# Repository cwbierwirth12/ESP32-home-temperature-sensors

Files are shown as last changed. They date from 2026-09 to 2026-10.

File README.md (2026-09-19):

# ESP32-Home-Temperature-Sensors

The purpose of this project is to deploy small ESP32 temperature and humidity sensors throughout your home and monitor them over your local network. This project uses ESPHome firmware, a Mosquitto MQTT broker, and a Node-RED diagnostic dashboard. ESPTH is the collection-only device utilizing an ESP32-C6 board; ESPTHSC adds a desktop display and online weather on an ESP32-S3 board. Home Assistant is an optional adaptation to be able to see your sensors, with no setup instructions included here.

This project is not turn-key. Users will need to configure the sensors for their home networks and make any adjustments necessary. Additionally the chips, boards, sensors all come bare bones and need to be assembled. 3D STL files are available for download to 3D print enclosures. At this time I do not know of any commercially available enclosures.

## Quickstart

1. Build the physical sensor (screen or no screen)
2. Copy `firmware/secrets.example.yaml` to private `firmware/secrets.yaml` and configure your network and location.
3. Compile the matching YAML with ESPHome and flash the resulting firmware over USB.
4. Choose a [Node-RED build](nodered/): a small one-sensor diagnostic flow or an always-on Raspberry Pi dashboard with SQLite history.
5. Connect sensors to power source
6. Connect to the Node-Red dashboard in your browser to monitor the temperatures. 

## Project Folders

  [firmware](firmware/) - ESPHome YAML templates, wiring pinouts, and USB/OTA installation instructions. ESPHome compiles the firmware; ESPHome Web flashes a compiled file. Private `secrets.yaml` and generated firmware are excluded by `.gitignore`.

  [Node-RED](nodered/) - Contains both a basic one-sensor diagnostic flow and a Raspberry Pi Zero 2W standalone build with multi-sensor SQLite history.

  [hardware](hardware/) - BOMs, Photos, and 3D STL files for the sensors

## Network and Ports

```text
Sensor
    |
    |
Home Network ------- Home Assistant (optional; instructions not included)
    |
    |
MQTT Broker
    |
    |
    |
Node-RED
```

| Service | Port | Used by |
| --- | --- | --- |
| MQTT broker | TCP `1883` | ESP32 devices and Node-RED connect to Mosquitto. |
| Node-RED editor and dashboard | TCP `1880` by default | Browser connects to the Node-RED computer; the port may differ if the user changed their Node-RED configuration. |
| ESPHome Device Builder | TCP `6052` by default | Browser connects to the firmware-building computer. |
| ESPHome OTA | TCP `3232` by default on ESP32 | ESPHome uploads firmware to a sensor with OTA enabled. |

For a standard local Node-RED installation, the editor is [localhost:1880](http://localhost:1880). The basic diagnostic flow uses `/dashboard/diagnostics`; the Raspberry Pi standalone build uses `/dashboard/temperature-history`. Use the port configured by your own installation if it differs. Use the server's LAN address from another device. No router port forwarding is required. Screen weather and time synchronization need internet access; local MQTT sensor collection does not.

## Tools and Software

- Firmware: ESPHome Device Builder; Docker is optional.
- DNode-Red Dashboard: a user-installed Node-RED instance plus the FlowFuse Dashboard add-on. Import the supplied diagnostic flow through the Node-RED editor.
- MQTT Broker: Mosquitto and its command-line clients.
- Enclosures: a 3D slicer of your choice.

Instructions for download and installation are found in each of the respective subfolders.

## Project Status and Disclosure

- I am not a programmer. Firmware, flow code, and documentation were developed with AI assistance. See [NOTICE.md](NOTICE.md) for attribution, third-party licenses, and testing limitations.

- This project is provided without warranty and is not intended for life-safety systems.

- This project is actively evolving. The screen enclosure is still in development, and the [firmware limitations](firmware/README.md#known-limitations) need review before calling the display firmware release-ready. Back up working configurations before upgrading.

- See the [publication review](AUDIT.md) for the checks performed, tested versions, and remaining hardware-validation work.

- Original project material is licensed under GNU GPL version 3 only (`GPL-3.0-only`). See [LICENSE](LICENSE) and [NOTICE.md](NOTICE.md). Third-party materials retain their own licenses.

# Project Thanks

- Huge thank you to my Sister for getting these components for me for Christmas 2025. Love you, sis.
- Thank you to my wife, for dealing with and embracing my nerdy endeavors.

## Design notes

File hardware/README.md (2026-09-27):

# Hardware and Enclosures

This folder documents the physical parts and 3D-printed enclosures for the two ESP32 Home Temperature Sensor variants:

- **ESPTH**: a compact, no-screen temperature and humidity sensor intended for data collection.
- **ESPTHSC**: a screen-equipped small temperature and humidity display intended for desktop use.

The firmware setup, pin wiring, and software configuration are documented in the [firmware README](../firmware/README.md).

## Contents

- [ESPTH bill of materials](#espth-bill-of-materials)
- [ESPTHSC bill of materials](#espthsc-bill-of-materials)
- [ESPTHSC display and controls](#espthsc-display-and-controls)
- [Enclosures and assembly](#enclosures-and-assembly)
- [3D-printing guidance](#3d-printing-guidance)
- [Troubleshooting](#troubleshooting)
- [Availability](#availability)

## ESPTH bill of materials

The no-screen ESPTH is the small, collection-only sensor.

| Part | Notes |
| --- | --- |
| [Waveshare ESP32-C6-Zero](https://www.waveshare.com/product/mcu-tools/development-boards/esp32-c6-zero.htm) | The ESP32 controller board used for this build. |
| [Waveshare DHT22 temperature and humidity sensor](https://www.waveshare.com/dht22-temperature-humidity-sensor.htm) | Measures local temperature and humidity. |
| USB-C data/power cable | Use a cable that supports data for the initial firmware flash. A charge-only cable will not work for flashing. |
| Regulated 5 V USB power source, 1 A or greater recommended | This is a practical adapter recommendation for the project, not a published Waveshare minimum current requirement. See the power notes below. |
| [ESPTH STL files](./3D%20Print/espth_files/STL/) | Base, lid, and two holding plates. [Editable STEP files](./3D%20Print/espth_files/STEP/) are also included. |
| Sensor wiring | Three conductors for power, ground, and data; choose connectors or soldered leads to fit the enclosure. |
| M2 x 4 mm and M2 x 6 mm screws | The enclosure is designed around these sizes. This [M2 screw kit](https://www.amazon.com/dp/B0D3X4LJD2) is the set used during development. |

## ESPTHSC bill of materials

The ESPTHSC is the screen-equipped version. It shows local and remote weather information and is intended to live on a desk, shelf, or other visible spot.

| Part | Notes |
| --- | --- |
| [Waveshare ESP32-S3-LCD-1.9](https://www.waveshare.com/esp32-s3-lcd-1.9.htm) | ESP32-S3 board with built-in 1.9-inch display. |
| [Waveshare DHT22 temperature and humidity sensor](https://www.waveshare.com/dht22-temperature-humidity-sensor.htm) | Measures local temperature and humidity. |
| USB-C data/power cable | Use a data-capable cable for the first firmware flash. |
| Regulated 5 V USB power source, 1 A or greater recommended | Practical adapter recommendation; actual current varies with display, Wi-Fi, peripherals, and battery charging. |
| Optional 3.7 V 450 mAh 502535 LiPo battery | The [example battery](https://www.amazon.com/dp/B0GDQMKQ36) is useful as short-term backup power while moving the display between rooms or disconnecting it from a computer. It is not intended to replace normal USB power. **Check the connector before ordering:** Waveshare documents an MX1.25 battery header on this board, while this example battery is listed with a JST-PH 2.0 connector. Use an appropriate adapter or a battery with the correct connector; never force a connector. |
| ESPTHSC enclosure files | Still in development; files will be added under [3D Print](./3D%20Print/) when ready. No screen STL or STEP files are currently included. |
| Sensor wiring | Three conductors for power, ground, and data. The supplied firmware uses `GPIO6` for the DHT22 data line. |
| M2 x 4 mm and M2 x 6 mm screws | This [M2 screw kit](https://www.amazon.com/dp/B0D3X4LJD2) is the set used during development. |

## ESPTHSC display and controls

The ESPTHSC firmware is configured for desktop use with the USB-C connector at the **9 o'clock / left-hand** side. It automatically advances every 20 seconds through this sequence:

1. Indoor temperature and humidity from the DHT22.
2. Indoor versus outside temperature comparison.
3. Current outdoor conditions, including wind speed and compass direction.
4. 12-hour outlook with two-hour samples for temperature, weather, precipitation, wind, and gust alerts.
5. Five-day forecast.
6. Moon phase.
7. Clock, network status, and battery estimate.

The physical **BOOT** button controls the display:

- **One short press:** wakes the display and advances to the next view. If clock-only mode is active, it exits that mode and returns to the indoor view.
- **Two short presses:** toggles clock-only mode. Enabling it opens the clock immediately; disabling it returns to the indoor view.
- **Press and hold for at least one second:** blanks the display. A later short press wakes it.

The short-press action waits 400 ms before it runs so the firmware can reliably distinguish a single press from a double press.

## Raspberry Pi Zero 2W Standalone  (OPTIONAL)

| Part | Notes |
| --- | --- |
| [Raspberry Pi Zero 2 W](https://www.waveshare.com/product/raspberry-pi/boards-kits/raspberry-pi-zero-2-w-cat/raspberry-pi-zero-2-w.htm) | |
| [32 GB SD Card](https://www.amazon.com/SanDisk-Ultra%C2%AE-microSDHC-120MB-Class/dp/B08L5HMJVW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)| |
| Micro-USB Cable |
| Regulated 5 V USB power source, 2.5 A or greater recommended | Practical adapter recommendation; actual current varies with display, Wi-Fi, peripherals, and battery charging. |

### Power and Battery Notes

Waveshare's [C6-Zero FAQ](https://docs.waveshare.com/ESP32-C6-Zero/FAQ) associates USB instability with supply voltage falling below 4.9 V. Its [board description](https://docs.waveshare.com/ESP32-C6-Zero) lists an 800 mA maximum output for the onboard 3.3 V regulator; that is not the board's measured current draw or a USB-adapter requirement. A regulated 5 V adapter rated for 1 A or more is the project's practical starting recommendation for either build. A higher current rating provides capacity; the board draws what it needs.

The [screen-board documentation](https://docs.waveshare.com/ESP32-S3-LCD-1.9) specifies a 3.7 V battery interface with an MX1.25 connector. The linked battery's JST-PH 2.0 plug is not a direct fit. Before use, verify the exact connector, positive/negative polarity, cell charging limits, and available case space. An adapter's physical fit alone does not establish electrical compatibility. Do not compress, puncture, or use a damaged or swollen LiPo cell.

The optional battery is intended to bridge short USB disconnections while moving the display. Continued power can preserve its in-memory state, but uninterrupted operation and runtime have not been verified for the linked pack. It does not preserve Wi-Fi connectivity between networks, guarantee MQTT delivery, or provide historical data storage.

## Enclosures and assembly

The current printable ESPTH files are in [3D Print/espth_files](./3D%20Print/espth_files/). Flash, configure, and test the boards before closing the enclosure. Disconnect USB and any battery before wiring or assembly. [Build photos](./Photos/espth/) show the no-screen enclosure.

- The STL filenames identify their purpose: base, lid, ESP32-C6 holding plate, and DHT22 holding plate.
- The thin holding plates secure the electronics inside the case.
- Use **M2 x 4 mm** screws for the internal holding plates.
- Use **M2 x 6 mm** screws to attach the lid to the base.
- The screw holes are countersunk for the heads in the recommended screw kit.
- Editable STEP versions are included for anyone who wants to adapt the design for different hardware, mounting locations, or preferences.

The ESPTHSC enclosure is currently in development and will be released here once it is ready.

## 3D-printing guidance

These enclosures are not highly structural parts, so use the material and printer settings that work best for you.

- PLA or PETG can be used; PETG is the maintainer's preference. Choose settings appropriate to your printer and filament.
- The maintainer used **20% infill** for these lightly loaded enclosures. Check fit and strength on your printer before final assembly.
- The DHT22 has a power indicator LED. It may shine through translucent or light-colored filament; that is normal.
- For installations with several sensors nearby, add a number to each case and fill it with acrylic paint or nail polish. It makes individual devices much easier to identify later.

Keep the sensor away from direct sunlight, HVAC vents, radiators, computers, and other heat sources. The enclosure protects the components, but it cannot make a poor measuring location accurate.

## Troubleshooting

| Symptom | Things to check |
| --- | --- |
| The board does not power on or repeatedly restarts | Try another USB-C cable and a known-good 5 V, 1 A or greater USB power source. The ESP32-C6-Zero documentation notes that its USB supply should remain at least 4.9 V. |
| The board cannot be flashed | Use a USB data cable, not a charge-only cable. Try a different USB port. For the C6-Zero, hold **BOOT**, press and release **RESET**, then release **BOOT** to enter download mode. |
| No temperature or humidity reading | Recheck the wiring and the pins listed in the [firmware README](../firmware/README.md). Make sure the correct YAML file is flashed for the hardware you built. |
| Measurements seem inaccurate | Give the sensor time to acclimate after power-up or moving it. Relocate it away from sunlight, airflow, warm electronics, or walls that hold heat. |
| The enclosure does not close cleanly | Confirm that the correct holding plate is installed, the components are seated fully, and M2 x 4 mm screws are only used for the internal plates. Do not overtighten plastic parts. |
| Battery will not connect to the ESPTHSC board | Stop and compare the battery plug with the board's MX1.25 header. Do not force a JST-PH 2.0 plug onto a different connector. |

## Availability

Pre-built systems and printed cases are not available for purchase at this time. This is a build-it-yourself project: the files, parts list, and firmware are provided so you can make and modify the system yourself.

This guide was developed with AI assistance. Project enclosure files and photographs are covered by [GPL-3.0-only](../LICENSE); see [NOTICE.md](../NOTICE.md) for attribution and third-party exceptions. The documentation does not claim that the CAD models or photographs were AI-generated.

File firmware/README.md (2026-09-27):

# Firmware Setup

This guide explains how to configure and install the ESPHome firmware for the two sensor styles in this project. The supplied examples are built for an MQTT broker and Node-RED dashboard. They are not turnkey firmware: you must enter your own Wi-Fi, MQTT, and display-location settings before flashing.

## Contents

- [Choose a hardware type](#choose-a-hardware-type)
- [Understand the names](#understand-the-names)
- [Wire the hardware](#wire-the-hardware)
- [Install the required software](#install-the-required-software)
- [Choose a flashing method](#choose-a-flashing-method)
- [Configure private settings](#configure-private-settings)
- [Configure the no-screen sensor](#configure-the-no-screen-sensor-espth)
- [Configure the screen sensor](#configure-the-screen-sensor-espthsc)
- [Closing notes](#closing-notes)
- [Known limitations](#known-limitations)

## Choose a hardware type

There are two distinct devices in this project. Pick the YAML file that matches the device you built.

| Type | YAML file | Purpose |
| --- | --- | --- |
| No-screen sensor | `espth-1.yaml` | A small, low-cost collection sensor. It reads temperature and humidity and publishes them to MQTT for Node-RED or another subscriber. |
| Screen sensor | `espthsc-1.yaml` | A more capable desk/display tool. It has a local indoor sensor, a color screen, weather data, a clock, and optional MQTT support. |

The no-screen build is intended to be placed wherever you need a measurement. The screen build is meant to be useful on its own at a desk, counter, or other visible location.

These examples were developed around the following hardware:

- **No-screen:** Waveshare [ESP32-C6](https://www.waveshare.com/esp32-c6-zero.htm), using the ESP32-C6-DevKitC-1-compatible board definition, plus a **DHT22** temperature/humidity sensor.
- **Screen:** Waveshare [ESP32-S3 1.9inch Display Development Board](https://www.waveshare.com/esp32-s3-lcd-1.9.htm), plus a **DHT22** temperature/humidity sensor.

The boards and sensors can be changed, but doing so requires updating the board definition, pin assignments, and possibly the display or sensor components in the YAML. Project-specific parts lists and enclosure information belong in the [hardware BOMs](../hardware/).

## Understand the names

Device names use a short, repeatable convention:

- `ESP` = ESP32-based device.
- `TH` = temperature and humidity sensor.
- `SC` = screen-equipped version.

Examples:

- `espth-1` means the first ESP32 temperature/humidity collection sensor.
- `espthsc-1` means the first ESP32 temperature/humidity sensor with a screen.

The examples use `espth-1` and `espthsc-1`. Change `device_name` and `friendly_name` in `substitutions:` for additional sensors. Keep every device name unique so that MQTT topics and ESPHome build folders do not collide.

## Wire the hardware

Disconnect USB power before changing any wiring. Double-check labels on your particular sensor breakout before applying power; clones and breakout boards do not always place the pins in the same physical order.

### No-screen sensor: ESP32-C6 and DHT22

The no-screen YAML expects the DHT22 data pin on `GPIO4`.

| DHT22 connection | Connect to ESP32-C6 |
| --- | --- |
| `VCC` or `+` | `3V3` |
| `DATA`, `OUT`, or `S` | `GPIO4` |
| `GND` or `-` | `GND` |

If you are using a bare four-pin DHT22 rather than a breakout module, add the pull-up resistor specified by the DHT22 documentation between `VCC` and `DATA`. Many ready-made DHT22 breakout boards already include it. The remaining bare-sensor pin is not connected.

### Screen sensor: ESP32-S3 display board and DHT22

The LCD, backlight, and BOOT button are already built into the Waveshare ESP32-S3 display board. No display wiring is required. Connect the external DHT22 sensor:

| DHT22 connection | Connect to ESP32-S3 display board |
| --- | --- |
| `VCC` or `+` | `3V3` |
| `DATA`, `OUT`, or `S` | `GPIO6` |
| `GND` or `-` | `GND` |

If you are using a bare four-pin DHT22 rather than a breakout module, add the pull-up resistor specified by the DHT22 documentation between `VCC` and `DATA`. Many ready-made DHT22 breakout boards already include it. The remaining bare-sensor pin is not connected.

The intended desktop orientation places the USB-C connector at the **9 o'clock / left-hand** side. The YAML uses `rotation: 270`. Using another orientation requires revising both rotation and drawing coordinates. Some views still contain portrait-sized coordinates and need correction for this landscape layout; see [Known limitations](#known-limitations).

## Install the required software

### ESPHome

ESPHome reads the YAML configuration, builds the firmware, and installs it on the ESP32. The simplest choice for most people is the **ESPHome Device Builder** desktop application.

1. Open the official [ESPHome installation page](https://esphome.io/install/).
2. Download the Device Builder for your operating system and complete its installation steps.
3. Open Device Builder. It will open a local browser dashboard where you can import and edit these YAML files.

For a first walk-through of the dashboard, see [Getting Started with ESPHome](https://esphome.io/install/getting-started/).

### Docker (optional)

Docker is **not required**. Use it only if you already prefer running ESPHome in a container instead of installing the Device Builder directly.

1. Install [Docker Desktop](https://www.docker.com/products/docker-desktop/).
2. Follow ESPHome's [Docker installation guide](https://esphome.io/install/docker/) to run the Device Builder against the folder that contains your YAML files.

A typical Docker Desktop setup on macOS does not provide direct USB serial passthrough for the first flash. Use the ESPHome Device Builder desktop app or a browser-based serial installer. Once the device is on Wi-Fi and OTA is enabled, future updates can be sent over the network.

### MQTT and Node-RED

The included collection-sensor example expects an MQTT broker and is designed to feed a Node-RED dashboard. Install and configure these separately:

- [Mosquitto MQTT broker](https://mosquitto.org/download/)
- [Node-RED](https://nodered.org/docs/getting-started/)

The firmware does not install or configure either service for you. Record the broker's local address, port, username, and password before continuing.

## Choose a flashing method

Every brand-new ESP32 needs its **first** firmware install over a USB data cable. OTA means *over the air*: it becomes available only after that first install succeeds and the device joins your Wi-Fi network.

### Method A: build and install with ESPHome Device Builder

This is the recommended method.

1. Connect the board to your computer with a USB **data** cable. Many charging-only cables will power the board but cannot flash it.
2. Open ESPHome Device Builder.
3. Add the YAML for your device and its private `secrets.yaml` to the Device Builder configuration directory. If your version offers file import, use it; otherwise copy the files into that directory and refresh the dashboard. Keep both files together so `!secret` resolves.
4. Complete the configuration steps below before clicking **Install**.
5. Click **Install** and choose the USB/serial option for the first flash.
6. Select the device's serial port when prompted. Allow the build to complete and wait for the upload confirmation.
7. After the device joins Wi-Fi, use **Install** again and choose the wireless option for later updates.

ESPHome's official [physical connection guide](https://esphome.io/guides/physical_device_connection/) covers common USB and board-connection problems.

### Method B: build a firmware file and flash it manually

Use this method when you want a reusable `.bin` firmware file or need a separate flashing tool.

1. Import and configure the YAML in ESPHome Device Builder.
2. Open the device menu, choose **Install**, then choose **Manual download**.
3. Save the generated firmware file. Choose the factory/first-install format when ESPHome offers that choice for a new board.
4. Open [ESPHome Web](https://web.esphome.io/) in Google Chrome or Microsoft Edge. These browsers support the USB connection the installer needs.
5. Connect the board with a USB data cable, click **Connect**, and allow the browser permission prompt.
6. Select the serial device that belongs to the board, click **Install**, then select the `.bin` file you downloaded.
7. Wait for the upload to complete, power-cycle the board if prompted, and confirm that it joins Wi-Fi.

Do not commit generated `.bin` files to this repository. The YAML is the source of truth; each user should build firmware for their own board and settings.

## Configure private settings

### 1. Keep credentials out of GitHub

The published starter file is [secrets.example.yaml](secrets.example.yaml). Before building:

1. Copy `secrets.example.yaml` to a private file named `secrets.yaml` in the same `firmware/` folder.
2. Enter your real credentials only in the private `secrets.yaml`.
3. Keep the root `.gitignore`, which already excludes private settings and build outputs, including:

```gitignore
secrets.yaml
*.bin
.esphome/
```

Never publish a Wi-Fi network name, Wi-Fi password, MQTT password, home IP address, or exact latitude/longitude.

### 2. Set Wi-Fi details

In your private `secrets.yaml`, replace the example values with your own network details:

```yaml
wifi_ssid: "YOUR_WIFI_SSID"
wifi_password: "YOUR_WIFI_PASSWORD"
```

ESPHome resolves `!secret wifi_ssid` and `!secret wifi_password` from this file automatically when the YAML and `secrets.yaml` are in the same folder.

### 3. Add MQTT details for the Node-RED path

For a GitHub-safe configuration, keep MQTT details in the same private secrets file:

```yaml
mqtt_broker: "YOUR_MQTT_BROKER_OR_LOCAL_ADDRESS"
mqtt_username: "YOUR_MQTT_USERNAME"
mqtt_password: "YOUR_MQTT_PASSWORD"
```

Both YAMLs already use these `!secret` keys. Both connect to Mosquitto on TCP `1883`. The Node-RED browser port, `1880`, is a different service and must not be entered as the MQTT port. For the temporary anonymous broker test, use empty strings for `mqtt_username` and `mqtt_password`.

### 4. Set fallback and OTA passwords

Replace `fallback_ap_password` with your own 8-63 character password for the setup hotspot. Replace `ota_password` with a private password for wireless firmware updates. The hotspot name is generated from the device name. OTA listens on TCP `3232` by default on these ESP32 devices; it is already enabled for ESPTHSC and optional for ESPTH.

### 5. Set the screen weather location and timezone

For ESPTHSC, change `timezone` in your private secrets file to your IANA timezone. `Etc/UTC` is a neutral example. In `weather_url`, replace `YOUR_LATITUDE` and `YOUR_LONGITUDE` with your weather location. Set the URL's `timezone=` parameter to the same timezone, encoding `/` as `%2F`; the example uses `Etc%2FUTC`. Keep the supplied current, hourly, and daily weather fields, units, and forecast lengths because the display parser expects them.

These values are read through `!secret timezone` and `!secret weather_url`, so you do not need to put a location in the public screen YAML. The no-screen device does not use these two keys. Open-Meteo receives the coordinates when the display fetches weather; see its [data attribution and terms](https://open-meteo.com/en/terms).

## Configure the no-screen sensor (`espth`)

Open `espth-1.yaml`. This YAML is for the collection-only sensor: an ESP32-C6 board with a DHT22 connected to `GPIO4`.

1. **Name the device.** Set `device_name` and `friendly_name` under `substitutions:`. The example is `espth-1`.
2. **Configure MQTT.** Set the broker, username, and password. Prefer the `!secret` approach described above. Leave `discovery: false` if you are using the included Node-RED approach.
3. **Confirm Wi-Fi.** The file already uses `!secret wifi_ssid` and `!secret wifi_password`. Make sure your private `secrets.yaml` contains those keys.
4. **Set fallback-hotspot credentials.** Set `fallback_ap_password` in private `secrets.yaml`. The hotspot appears when normal Wi-Fi cannot be joined; `captive_portal:` enables its setup page.
5. **Confirm the hardware settings.** The supplied build expects a DHT22 on `GPIO4` and reports temperature in Fahrenheit every 15 minutes. Change the model, pin, units, or update interval only if your hardware or desired behavior differs.
6. **Enable OTA if you want wireless updates.** The `ota:` section is commented out in this sample. Remove the comment and use the current ESPHome form:

```yaml
ota:
  - platform: esphome
    password: !secret ota_password
```

7. Save the file, validate/build it in ESPHome, and perform the first USB flash.

After connection, the device publishes to `<device_name>/sensor/temperature/state` and `<device_name>/sensor/humidity/state`. Allow up to 15 minutes for the next DHT22 sample; temporarily shorten `update_interval` while diagnosing. Follow the [included Node-RED setup](../nodered/README.md) and select `<device_name>/sensor/+/state` to verify the data path. `npm start` loads the flow automatically.

## Configure the screen sensor (`espthsc`)

Open `espthsc-1.yaml`. This is the display-oriented build for the Waveshare ESP32-S3-LCD-1.9 and DHT22 sensor.

### What the display does

The screen advances through seven views every 20 seconds unless blanked or in clock-only mode. The sequence is intentionally ordered from indoor measurements to the broader outdoor view:

1. **Inside sensor:** local DHT22 temperature and humidity.
2. **Inside vs. outside:** a side-by-side temperature comparison and difference.
3. **Outside now:** current outside temperature, humidity, wind speed, and compass direction from Open-Meteo.
4. **12-hour outlook:** two-hour samples for temperature, weather, precipitation, wind, and gust alerts.
5. **Five-day outlook:** daily high/low trend, precipitation, and gust alerts.
6. **Moon phase:** current moon phase plus upcoming new/full moon dates.
7. **Clock:** time, date, Wi-Fi state, device IP address, and battery estimate when available.

The board's physical **BOOT** button has three commands:

- **Short press:** wake the display and advance to the next view. If clock-only mode is active, it exits that mode and returns to the inside-sensor view.
- **Double short press:** enter or leave clock-only mode. Entering the mode opens the clock immediately; leaving it returns to the inside-sensor view.
- **Press and hold for at least one second:** blank the display. A later short press wakes it again.

The single-click action waits 400 ms before it runs, allowing the firmware to distinguish a single press from a double press more reliably.

### Reliability behavior

- MQTT telemetry can publish available indoor temperature, humidity, battery percentage, and a Unix timestamp every minute to `<device_name>/telemetry` when its commented configuration and publish action are enabled.
- MQTT is optional to the display itself. If the broker cannot be reached, the display stays running rather than rebooting. The broker must be reachable from the ESP32's Wi-Fi network; a VPN running only on a computer does not provide the ESP32 a route to that broker.
- The clock saves a snapshot, but it is not a battery-backed real-time clock. Do not rely on that saved timestamp after a restart; see the limitations below. Weather is cached in RAM while powered. The display disables ESPHome's Wi-Fi reboot timeout, so it keeps that cache while waiting for a temporary hotspot to return. A manual or power-cycle reboot still clears cached weather.
- The DHT22 updates every 30 seconds. A missing reading normally points to power, data-line, pull-up-resistor, or sensor-compatibility issues.

### Screen YAML configuration checklist

1. **Name the device.** Set `device_name` and `friendly_name` under `substitutions:`. The example is `espthsc-1`.
2. **Set Wi-Fi, fallback-hotspot, and OTA details.** Enter the private values in `secrets.yaml`; the screen YAML already references them.
3. **Set your timezone.** Change `timezone` in private `secrets.yaml`.
4. **Set the weather location.** Replace the coordinate placeholders in private `weather_url` as described above.
5. **Make both timezones agree.** Keep `timezone` and the weather URL's `timezone=` parameter in sync so forecast hours line up with the clock.
6. **Enable MQTT only if needed.** The sample preserves a commented MQTT block and telemetry action. Uncomment both, then set the three `mqtt_*` values in private `secrets.yaml` to publish the one-minute telemetry feed. The display can operate without MQTT.
7. **Leave sensor/display pins alone unless you changed hardware.** This YAML expects a DHT22 data line on `GPIO6`. Different boards, displays, or sensors require their own pin/component changes.
8. Save the file, build it, and perform the first USB flash. This YAML already includes the ESPHome OTA component, so later updates can be sent over Wi-Fi after the device is connected.

## Closing notes

- Keep one backup of every working YAML before experimenting with changes.
- Give every device a unique name and MQTT log topic.
- Check the ESPHome logs after flashing. They are the fastest way to find a wrong Wi-Fi password, MQTT address, or disconnected sensor.
- The included firmware is designed around MQTT and Node-RED. ESPHome can also be adapted for Home Assistant's native API, but that alternate setup is not documented or supported by this project.
- Treat the display's weather location, network settings, and credentials as private configuration. Share only the cleaned template YAML files.

For project-wide context, return to the repository [README](../README.md).

## Known Limitations

Both supplied YAMLs compiled successfully with ESPHome 2026.8.2 during the [publication review](../AUDIT.md). Compilation is not a substitute for testing the actual boards.

- Several display views use Y coordinates beyond 170 even though `rotation: 270` creates a 320 x 170 drawing area. Those elements can be clipped. The five-day and moon layouts use landscape coordinates; the other views need a consistent layout pass and physical-board testing.
- The saved-clock fallback persists a `millis()` reference from the previous boot. Since `millis()` resets, its elapsed-time calculation is not reliable across restarts. A battery can help avoid a restart while moving the device, but it does not make this a reliable clock or data recorder.
- The voltage-based battery percentage is a rough estimate, not a measured state of charge. MQTT readings are not queued for later delivery through a network outage.
- Weather currently uses plain HTTP with `verify_ssl: false`; coordinates and weather requests are not encrypted in transit. HTTPS support and certificate validation need testing with the chosen ESPHome framework before changing this behavior.
- Moon phase and dates are approximate. They are not astronomical predictions for precise timing.
- ESPHome 2026.8.2 warns that `neopixelbus` and `st7789v` are deprecated; migrations to `esp32_rmt_led_strip` and `mipi_spi` need testing before a future ESPHome upgrade. It also flags GPIO4 on the C6 and GPIO0 on the S3 as strapping pins. These are the existing wiring/BOOT assignments; check startup behavior on your boards rather than suppressing the warnings.

Firmware and this guide were developed with AI assistance. Original project files use [GPL-3.0-only](../LICENSE); see [NOTICE.md](../NOTICE.md) for attribution and validation limits.

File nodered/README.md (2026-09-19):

# Node-RED Builds

This folder has two different Node-RED paths. Both receive ESP32 readings through Mosquitto on TCP `1883`, but they serve different purposes.

| Build | Best for | What it includes |
| --- | --- | --- |
| [Basic testing](../nodered/basic_testing/README.md) | Confirming one sensor, broker, and dashboard work | A small importable diagnostic flow and beginner MQTT guide |
| [Raspberry Pi Zero 2 W standalone dashboard](../nodered/pi_zero_2w_Standalone/README.md) | A permanent, whole-home local monitor | Pi OS setup, Mosquitto, SQLite history, a multi-sensor Dashboard 2.0 flow, and optional OpenWeather data |

Start with **Basic testing** when you are new to MQTT or Node-RED. Use the Raspberry Pi build when you want the dashboard and history database to run continuously without leaving a computer on.

Both flows are imported into a user-installed Node-RED instance. Neither flow contains private Wi-Fi details, MQTT credentials, database files, or API keys. Review a flow before exporting it from your own Node-RED installation.

Original project files are offered under [GPL-3.0-only](../LICENSE). See [NOTICE.md](../NOTICE.md) for attribution and AI-assistance disclosure.

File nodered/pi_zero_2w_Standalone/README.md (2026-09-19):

# Raspberry Pi Zero 2 W Standalone Dashboard

This guide turns a Raspberry Pi Zero 2 W into an always-on local server for the ESP32 Home Temperature Sensors project. The Pi receives MQTT readings from the sensors, saves them in a SQLite database, and hosts a Node-RED Dashboard 2.0 page for phones and computers on the same home network.

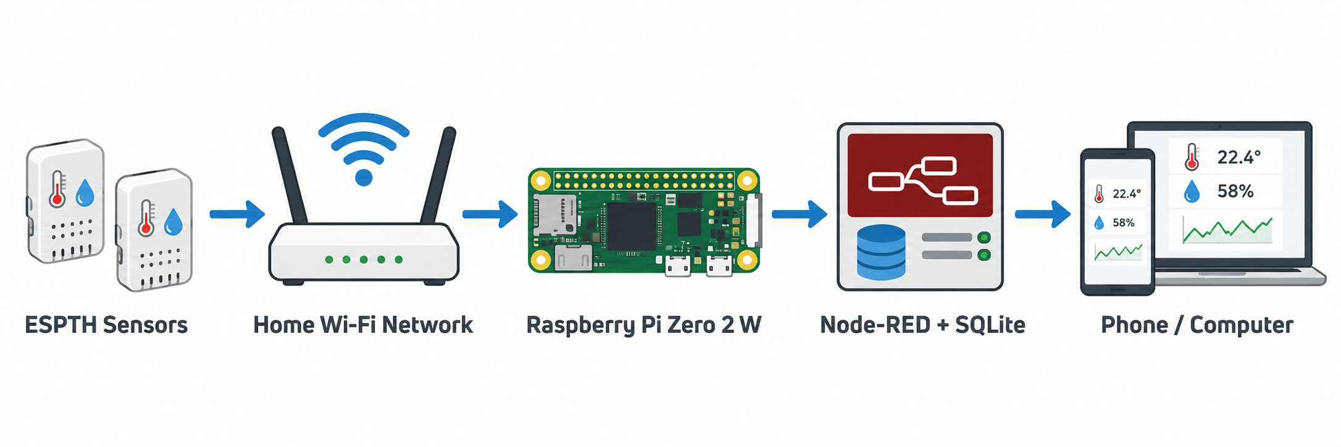
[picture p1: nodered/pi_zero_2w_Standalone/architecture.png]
ESPTH sensors connect through the home Wi-Fi network to a Raspberry Pi Zero 2 W running Node-RED and SQLite, then to a phone or computer.


The architecture illustration was generated with OpenAI image generation and is included as a project diagram, not a photograph of the supplied hardware.

## Contents

- [What you will build](#what-you-will-build)
- [Parts and accounts](#parts-and-accounts)
- [Flash Raspberry Pi OS](#flash-raspberry-pi-os)
- [Find the Pi and connect with SSH](#find-the-pi-and-connect-with-ssh)
- [Update the Pi and install base packages](#update-the-pi-and-install-base-packages)
- [Set up Mosquitto MQTT](#set-up-mosquitto-mqtt)
- [Set up Node-RED, Dashboard 2.0, and SQLite](#set-up-node-red-dashboard-20-and-sqlite)
- [Import and configure the standalone flow](#import-and-configure-the-standalone-flow)
- [Open the dashboard from a phone or computer](#open-the-dashboard-from-a-phone-or-computer)
- [Optional OpenWeather integration](#optional-openweather-integration)
- [Troubleshooting](#troubleshooting)

## What you will build

```text
ESPTH / ESPTHSC sensors -> home Wi-Fi -> Raspberry Pi
                                          |- Mosquitto MQTT broker
                                          |- SQLite history database
                                          `- Node-RED Dashboard 2.0
                                                        |
                                                        `-> phone or computer browser
```

The Pi is the central local computer for this setup. It should remain powered and connected to your normal home network. This guide uses MQTT on TCP `1883` and Node-RED on TCP `1880`. Do not forward either port from your internet router.

The supplied [pi-zero-2w-standalone-flow.json](pi-zero-2w-standalone-flow.json) is an importable Node-RED flow. It does not replace existing Node-RED flows.

## Parts and accounts

- Raspberry Pi Zero 2 W, case, and a quality microSD card of at least 16 GB.
- A stable 5 V, 2.5 A micro-USB power supply for the Pi.
- A computer running macOS, Windows, or Linux with an SD-card reader.
- Your Wi-Fi name and password. The Pi Zero 2 W supports 2.4 GHz Wi-Fi; ensure the network you enter in Raspberry Pi Imager is reachable on 2.4 GHz.
- The ESPTH or ESPTHSC sensors already assembled and ready to have their MQTT settings updated.

You will choose a Pi username, Pi password, and MQTT password during setup. Keep each private. Do not add them to this repository, screenshots, or exported Node-RED flows.

## Flash Raspberry Pi OS

Use **Raspberry Pi OS Lite (64-bit)**. It has no desktop environment, leaving more of the Pi's limited memory for the broker, database, and dashboard. The same imaging steps work from all three computer operating systems.

### macOS

1. Download [Raspberry Pi Imager](https://www.raspberrypi.com/software/) for macOS.
2. Open the downloaded installer and move Raspberry Pi Imager to Applications when prompted.
3. Open Raspberry Pi Imager from Applications.

### Windows

1. Download [Raspberry Pi Imager](https://www.raspberrypi.com/software/) for Windows.
2. Run the downloaded installer, accept the defaults, and open Raspberry Pi Imager from the Start menu.

### Linux

1. Download Raspberry Pi Imager from the official [Raspberry Pi software page](https://www.raspberrypi.com/software/).
2. On Debian, Ubuntu, Raspberry Pi OS, or another Debian-based distribution, you can also install it with:

```bash
sudo apt update
sudo apt install -y rpi-imager
rpi-imager
```

3. If your Linux distribution is not Debian-based, use the package or download linked on the Raspberry Pi software page.

### Write the card

1. Insert the microSD card into your computer.
2. In Raspberry Pi Imager, choose **Raspberry Pi Device** and select **Raspberry Pi Zero 2 W**.
3. Choose **Raspberry Pi OS (other)**, then choose **Raspberry Pi OS Lite (64-bit)**.
4. Choose the microSD card under **Storage**. Carefully verify the selected drive: Imager erases it.
5. Click **Next**. When Imager offers to customize the OS, choose **Edit Settings**.
6. On the **General** tab:
   - Set hostname to `tempsensor-pi`.
   - Set a username. In this guide, replace `YOUR_PI_USERNAME` with that exact username whenever it appears.
   - Set a strong password.
   - Enter your Wi-Fi network name and password, then choose your correct Wi-Fi country.
7. On the **Services** tab, enable **SSH** and choose **Use password authentication**. SSH keys are stronger, but password authentication is easier for a first setup.
8. Save the settings, choose **Yes** to write, and wait for writing and verification to finish.
9. Eject the card, insert it in the Pi, and connect power. Wait about two minutes for the first boot.

The hostname, Wi-Fi settings, username, and SSH setting are written privately to the new SD card. They are not part of this project or its example files.

## Find the Pi and connect with SSH

The hostname chosen above lets most home networks find the Pi as `tempsensor-pi.local`. The command below should print an IP address in its first line.

### macOS

Open Terminal and run:

```bash
ping -c 1 tempsensor-pi.local
```

Connect with:

```bash
ssh YOUR_PI_USERNAME@tempsensor-pi.local
```

### Windows

Open PowerShell and run:

```powershell
ping -n 1 tempsensor-pi.local
```

Connect with:

```powershell
ssh YOUR_PI_USERNAME@tempsensor-pi.local
```

### Linux

Open a terminal and run:

```bash
ping -c 1 tempsensor-pi.local
```

Connect with:

```bash
ssh YOUR_PI_USERNAME@tempsensor-pi.local
```

On the first SSH connection, type `yes` when asked whether to trust the Pi's host key, then enter the Pi password you created in Imager. You are now entering commands on the Pi itself; all remaining terminal commands in this guide are identical regardless of whether you started from a Mac, Windows PC, or Linux computer.

If `tempsensor-pi.local` does not resolve, open your router's connected-device list and find the device named `tempsensor-pi`, then use its IP address instead:

```bash
ssh YOUR_PI_USERNAME@YOUR_PI_IP_ADDRESS
```

After connecting, record the Pi's current network address with:

```bash
hostname -I
```

Use the first address on your home network in the ESPHome MQTT configuration and browser addresses below. A router may assign a different address later; reserve this address in the router if it offers DHCP reservations.

## Update the Pi and install base packages

Run these commands in the Pi SSH session:

```bash
sudo apt update
sudo apt full-upgrade -y
sudo reboot
```

The SSH connection will close during reboot. Wait about one minute, reconnect using the SSH command above, then install the packages needed by Mosquitto, SQLite, and Node-RED:

```bash
sudo apt install -y mosquitto mosquitto-clients sqlite3 build-essential git curl
```

Confirm the Pi has the correct local time before storing readings:

```bash
timedatectl status
```

If the time zone is wrong, set it interactively:

```bash
sudo raspi-config
```

Choose **5 Localisation Options**, then **L2 Timezone**, select your region and city, then finish and reboot if prompted.

## Set up Mosquitto MQTT

Mosquitto receives messages from the ESP32 sensors. This guide uses a dedicated MQTT account and allows connections only through the Pi's normal local network interface.

### 1. Create an MQTT account

Run this command and enter a new MQTT password when prompted. Do not use a password you intend to publish anywhere.

```bash
sudo mosquitto_passwd -c /etc/mosquitto/temperature-sensors.passwd temperature_sensor
```

### 2. Create the broker configuration

Copy and paste this complete block into the Pi SSH session:

```bash
sudo tee /etc/mosquitto/conf.d/temperature-sensors.conf > /dev/null <<'EOF'
listener 1883
allow_anonymous false
password_file /etc/mosquitto/temperature-sensors.passwd
EOF
```

Set safe file ownership and start the broker:

```bash
sudo chown root:mosquitto /etc/mosquitto/temperature-sensors.passwd
sudo chmod 640 /etc/mosquitto/temperature-sensors.passwd
sudo systemctl enable --now mosquitto
sudo systemctl restart mosquitto
sudo systemctl status mosquitto --no-pager
```

The last command should show `active (running)`. Press `q` if it opens a long status view.

### 3. Test MQTT locally

Open a second SSH session to the Pi. In the first session, start a subscriber. Replace `YOUR_MQTT_PASSWORD` with the password just created:

```bash
mosquitto_sub -h localhost -p 1883 -u temperature_sensor -P 'YOUR_MQTT_PASSWORD' -t 'test/temperature' -v
```

In the second SSH session, publish a test reading:

```bash
mosquitto_pub -h localhost -p 1883 -u temperature_sensor -P 'YOUR_MQTT_PASSWORD' -t 'test/temperature' -m '72.4'
```

The first session should show `test/temperature 72.4`. Press `Ctrl+C` there after the test. The `-P` examples place a password in command history, so do not share that terminal history or screenshots.

### 4. Point the ESP32 sensors at the Pi

In the private `firmware/secrets.yaml` used to build each sensor, set these values before flashing or sending an OTA update:

```yaml
mqtt_broker: "YOUR_PI_IP_ADDRESS"
mqtt_username: "temperature_sensor"
mqtt_password: "YOUR_MQTT_PASSWORD"
```

Keep `port: 1883` in the public ESPHome YAML. Use the Pi's LAN IP address rather than `localhost`; on an ESP32, `localhost` would mean the ESP32 itself. The screen firmware has MQTT commented out by default, so enable its MQTT block and telemetry publish action before expecting ESPTHSC readings on the Pi.

To watch all messages after flashing a sensor, run this on the Pi:

```bash
mosquitto_sub -h localhost -p 1883 -u temperature_sensor -P 'YOUR_MQTT_PASSWORD' -t '#' -v
```

You should see `espth-1/sensor/.../state` messages from the no-screen sensor or `<device_name>/telemetry` JSON messages from a screen sensor with MQTT enabled.

## Set up Node-RED, Dashboard 2.0, and SQLite

### 1. Install Node-RED as a Pi service

Run Node-RED's official Debian/Raspberry Pi installer. It installs Node.js and Node-RED, then configures Node-RED to run as a service:

```bash
bash <(curl -sL https://github.com/node-red/linux-installers/releases/latest/download/install-update-nodered-deb)
```

Read each installer prompt. When it finishes, start the service and view its log:

```bash
node-red-start
```

Wait until the log says Node-RED is running, then press `Ctrl+C`. This only closes the log view; the service keeps running in the background. Check it at any time with:

```bash
node-red-log
```

### 2. Install the dashboard and SQLite nodes

The flow requires the current FlowFuse Dashboard 2.0 package and the official Node-RED SQLite node. Run:

```bash
node-red-stop
cd "$HOME/.node-red"
npm install @flowfuse/node-red-dashboard node-red-node-sqlite
node-red-start
```

Wait for the service log to report that Node-RED is running, then press `Ctrl+C` to leave the log view. The dashboard is now available to the Pi's home network; it is not exposed to the public internet unless you deliberately change your router or firewall configuration.

### 3. Prepare the database location

Create a private directory for the database. This command also prints the exact path you will place in the Node-RED SQLite configuration:

```bash
mkdir -p "$HOME/temperature-dashboard"
printf '%s\n' "$HOME/temperature-dashboard/temperature-sensors.db"
```

The imported flow creates the tables and index automatically when deployed. You can confirm that SQLite can open the file with:

```bash
sqlite3 "$HOME/temperature-dashboard/temperature-sensors.db" '.databases'
```

## Import and configure the standalone flow

### 1. Open Node-RED

From a computer or phone on the same home network, open:

```text
http://YOUR_PI_IP_ADDRESS:1880
```

The first time you open it, Node-RED may show a welcome screen. You should see the flow editor, with a node palette on the left and workspace in the center.

### 2. Import the flow

1. Download [pi-zero-2w-standalone-flow.json](pi-zero-2w-standalone-flow.json) from this folder to the computer you are using.
2. In Node-RED, select the menu in the upper-right corner, then choose **Import**.
3. Choose **select a file to import**, select the downloaded JSON file, then click **Import**.
4. Place the imported **Pi Temperature Dashboard** tab in the workspace and click **Import** again if Node-RED asks for placement.

The flow adds a tab to Node-RED. It does not replace your other flows.

### 3. Set the SQLite database path

1. On the **Pi Temperature Dashboard** tab, double-click any purple **SQLite** node.
2. Next to **Database**, click the pencil icon.
3. In the file path field, replace `YOUR_PI_USERNAME` with the username you chose in Raspberry Pi Imager. The completed path must be:

```text
/home/YOUR_PI_USERNAME/temperature-dashboard/temperature-sensors.db
```

4. Set the database mode to **Read/Write/Create** if it is not already selected.
5. Click **Update**, then **Done**.

All SQLite nodes share that one database configuration, so this change applies to the whole flow.

### 4. Set MQTT credentials

1. Double-click the **All sensor MQTT messages** node.
2. Next to **Pi Mosquitto**, click the pencil icon.
3. Leave the server as `localhost` and port as `1883`. Mosquitto and Node-RED run on the same Pi.
4. Open the **Security** tab and enter username `temperature_sensor` and the MQTT password you created earlier.
5. Click **Update**, then **Done**.

### 5. Assign a location to each sensor

1. Double-click the **Normalize, locate, and store** function node.
2. At the top of the code, edit only the `locations` section. For example:

```javascript
const locations = {
    "espth-1": "Living Room",
    "espth-2": "Bedroom",
    "espthsc-1": "Desk Display"
};
```

Each key must exactly match the device name in that sensor's ESPHome YAML. The value is the human-readable name shown on the dashboard and saved in the database. Unknown sensor names are stored as `Unassigned (<device name>)`, making a missing assignment easy to spot.

### 6. Deploy and confirm storage

1. Click **Deploy** in the upper-right corner.
2. The **Initialize SQLite tables** node runs automatically once after deployment.
3. Watch the status under **All sensor MQTT messages**. It should change to `connected`.
4. Wait for a sensor reading. ESPTHSC telemetry is normally every minute when MQTT is enabled; ESPTH samples every 15 minutes.

The flow stores each valid MQTT update in SQLite. For separate ESPTH temperature and humidity state messages, two closely spaced records can be stored as the values arrive; the dashboard keeps the latest known temperature and humidity together.

To inspect the newest stored records directly on the Pi, run:

```bash
sqlite3 -header -column "$HOME/temperature-dashboard/temperature-sensors.db" "SELECT recorded_at, sensor_id, location, temperature_f, humidity_percent FROM sensor_readings ORDER BY id DESC LIMIT 10;"
```

## Open the dashboard from a phone or computer

Open this address while connected to the same home network:

```text
http://YOUR_PI_IP_ADDRESS:1880/dashboard/temperature-history
```

The page shows:

- The location, temperature, humidity, and timestamp from the most recently received sensor reading.
- A temperature history chart for the last 24 hours, with a separate line for each assigned location.
- A humidity history chart for the last 24 hours.
- Empty optional weather fields until OpenWeather is enabled.

On a phone, save the dashboard URL as a home-screen bookmark if you want it to behave like a small local app. Do not use a guest Wi-Fi network: guest networks often prevent phones from reaching the Pi.

## Optional OpenWeather integration

This part is optional. It fetches current outdoor weather from OpenWeather every 15 minutes, stores it in the same SQLite database, and shows it on the dashboard. It requires an OpenWeather account, API key, internet access for the Pi, and the coordinates you choose to share with OpenWeather.

1. Create an API key through [OpenWeather](https://openweathermap.org/api). Review its current plan, service terms, and privacy information before use.
2. In Node-RED, open the **Optional OpenWeather** tab. It is disabled by default.
3. Enable the tab, then double-click **Set OpenWeather request details**.
4. Replace the three placeholders at the top of the function with your API key, latitude, and longitude. Do not put those values into this repository or re-exported public flow.
5. Click **Done**, then **Deploy**.

The optional tab updates the **Outdoor Weather** group on the dashboard and writes rows to `weather_readings`. To verify the rows from SSH:

```bash
sqlite3 -header -column "$HOME/temperature-dashboard/temperature-sensors.db" "SELECT recorded_at, location, temperature_f, humidity_percent, description FROM weather_readings ORDER BY id DESC LIMIT 10;"
```

If you do not need outdoor weather, leave the tab disabled. The indoor sensor, database, and dashboard remain fully local.

## Troubleshooting

| Symptom | What to check |
| --- | --- |
| The Pi never appears on the network | Confirm the SD-card image used the correct Wi-Fi name, password, and country. The Pi Zero 2 W needs 2.4 GHz Wi-Fi. Check power, wait two minutes, then look for `tempsensor-pi` in the router's connected-device list. |
| SSH says connection refused or times out | Confirm SSH was enabled in Raspberry Pi Imager. Use the Pi's IP address instead of `.local`. Reflash with SSH enabled if necessary. |
| `mosquitto` is not active | Run `sudo systemctl status mosquitto --no-pager` and then `sudo journalctl -u mosquitto -n 50 --no-pager`. Recheck the configuration block and password-file permissions. |
| A sensor cannot connect to MQTT | Ensure its private `secrets.yaml` uses the Pi's LAN IP, port `1883`, and the same MQTT username/password. `localhost` is wrong in sensor firmware. Check the live broker with the `mosquitto_sub` command above. |
| Node-RED does not start | Run `node-red-log`. If memory is tight, the Pi installer provides `node-red-pi --max-old-space-size=256` for a foreground diagnostic run. Do not run two Node-RED instances on the same port. |
| Imported nodes say unknown or are red | On the Pi, run the Dashboard and SQLite install command again, then restart Node-RED. The flow needs `@flowfuse/node-red-dashboard` and `node-red-node-sqlite`. |
| SQLite reports it cannot open the database | Re-open the shared SQLite configuration node. Its path must use your actual Pi username and point to the directory created with `mkdir -p "$HOME/temperature-dashboard"`. |
| Dashboard opens but has no readings | Confirm the MQTT node says `connected`, then run the all-topics `mosquitto_sub` command on the Pi. Confirm the device name in the MQTT topic matches one supported by the normalizing function. Wait for the sensor's sample interval. |
| Dashboard location says `Unassigned (...)` | Add that exact device name to the `locations` object in **Normalize, locate, and store**, then deploy. |
| Charts are blank after restarting Node-RED | Confirm `sensor_readings` contains records with the SQLite query above. The flow loads the previous 24 hours on deployment; browser refresh or redeploy after fixing the database path. |
| OpenWeather shows no values | Keep the optional tab enabled, confirm the three placeholders were replaced, and check Node-RED's Debug sidebar or `node-red-log` for an HTTP/API error. |
| A phone cannot open the dashboard | Connect the phone to the normal home Wi-Fi, not cellular or guest Wi-Fi. Use `http://YOUR_PI_IP_ADDRESS:1880/dashboard/temperature-history`, not `localhost`. |

For broader MQTT testing and an intentionally small one-sensor example, see the [basic testing flow](../basic_testing/). Firmware setup and private sensor configuration are covered in the [firmware guide](../../firmware/README.md).

This guide and flow were developed with AI assistance and are offered under [GPL-3.0-only](../../LICENSE). See [NOTICE.md](../../NOTICE.md) for attribution, third-party terms, and limitations.

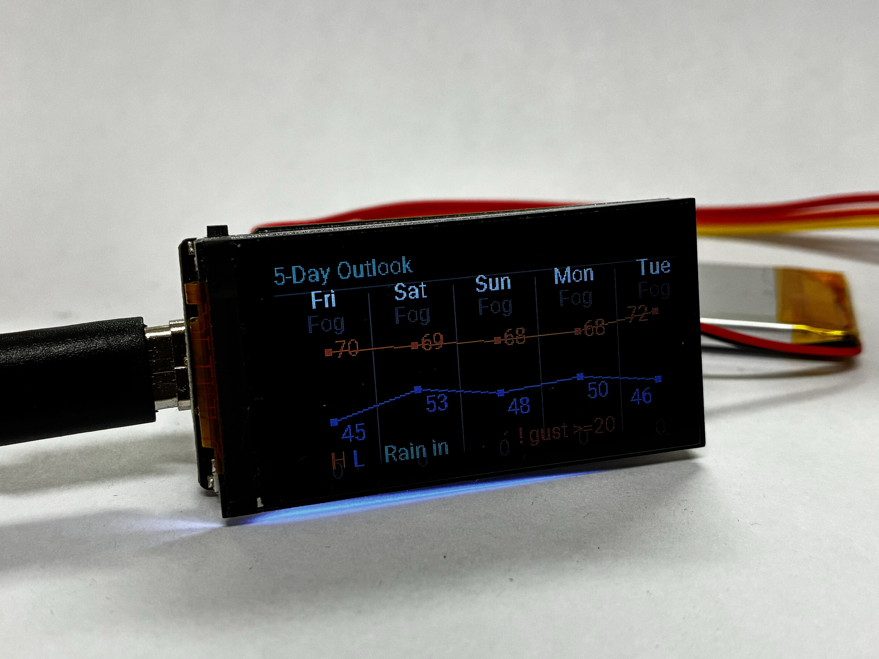
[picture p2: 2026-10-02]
hardware/Photos/espthsc/ESPTHSC-5.jpg

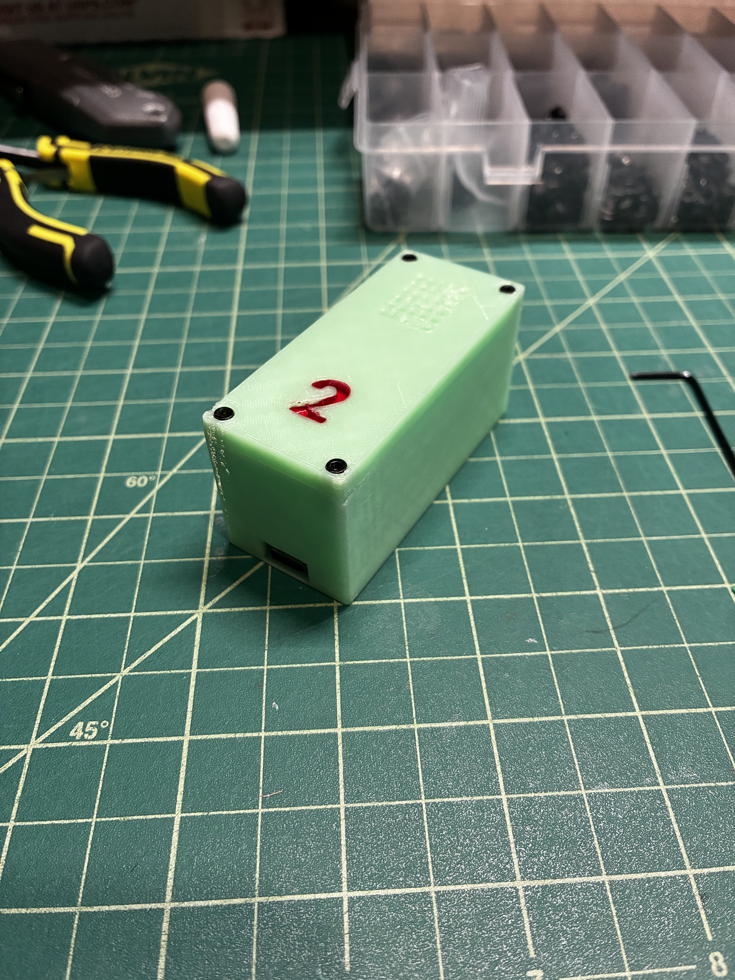
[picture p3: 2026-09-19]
hardware/Photos/espth/espth-enclosure-side.jpg

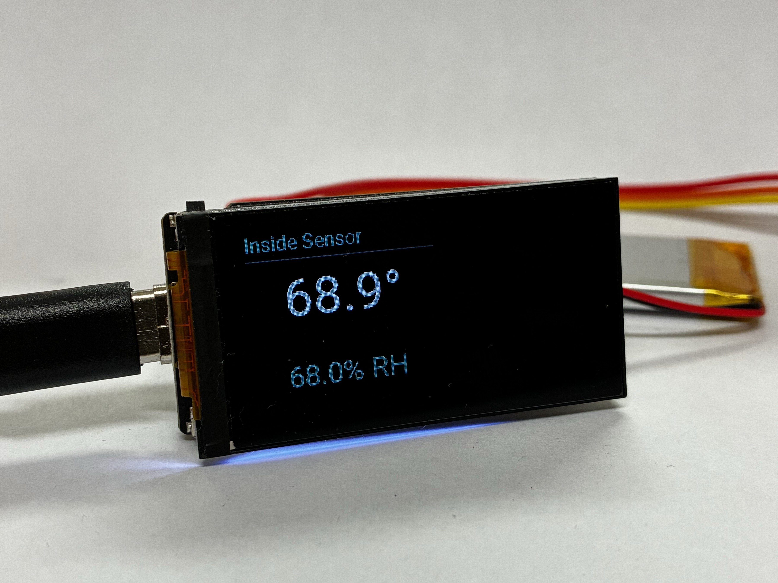
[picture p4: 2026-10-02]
hardware/Photos/espthsc/ESPTHSC-1.jpg

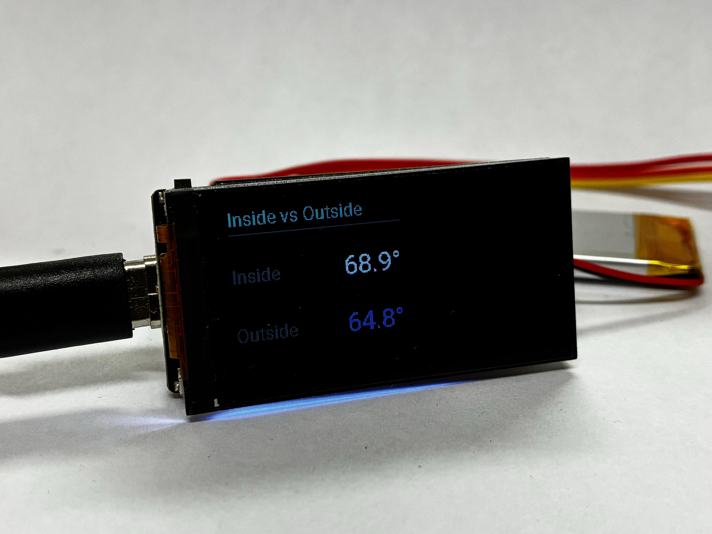
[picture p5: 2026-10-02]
hardware/Photos/espthsc/ESPTHSC-2.jpg

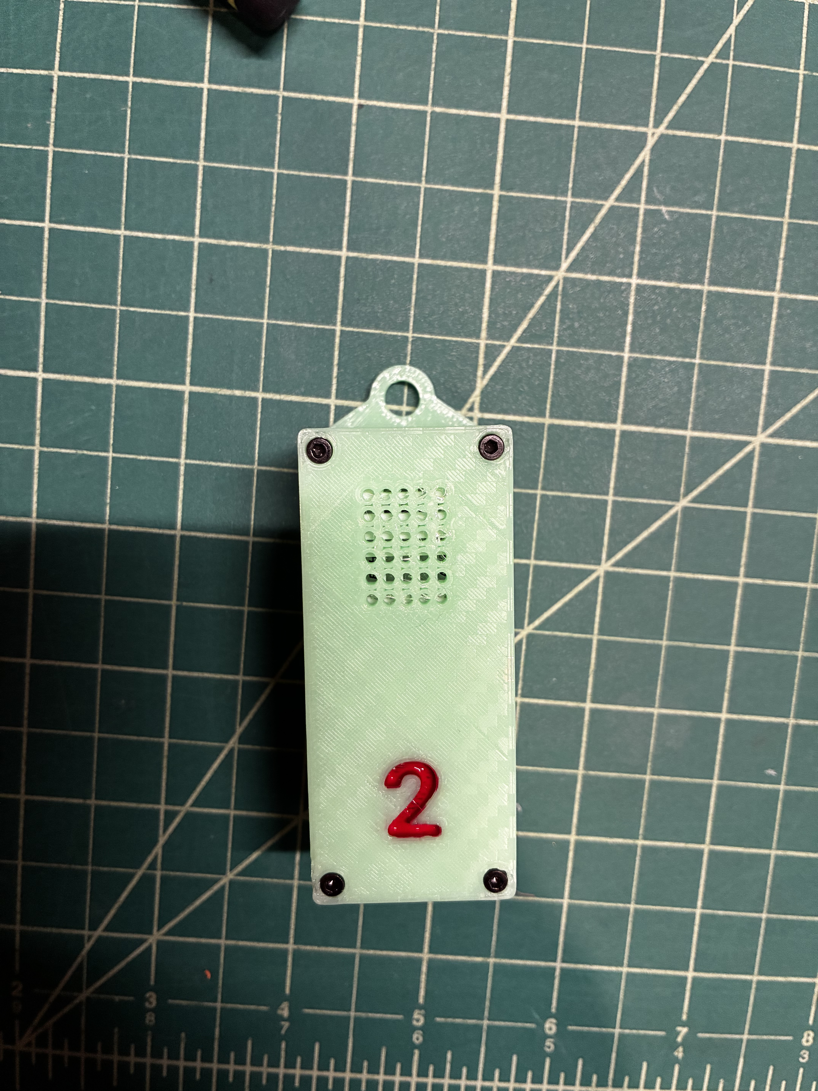
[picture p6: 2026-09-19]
hardware/Photos/espth/espth-enclosure-front.jpg

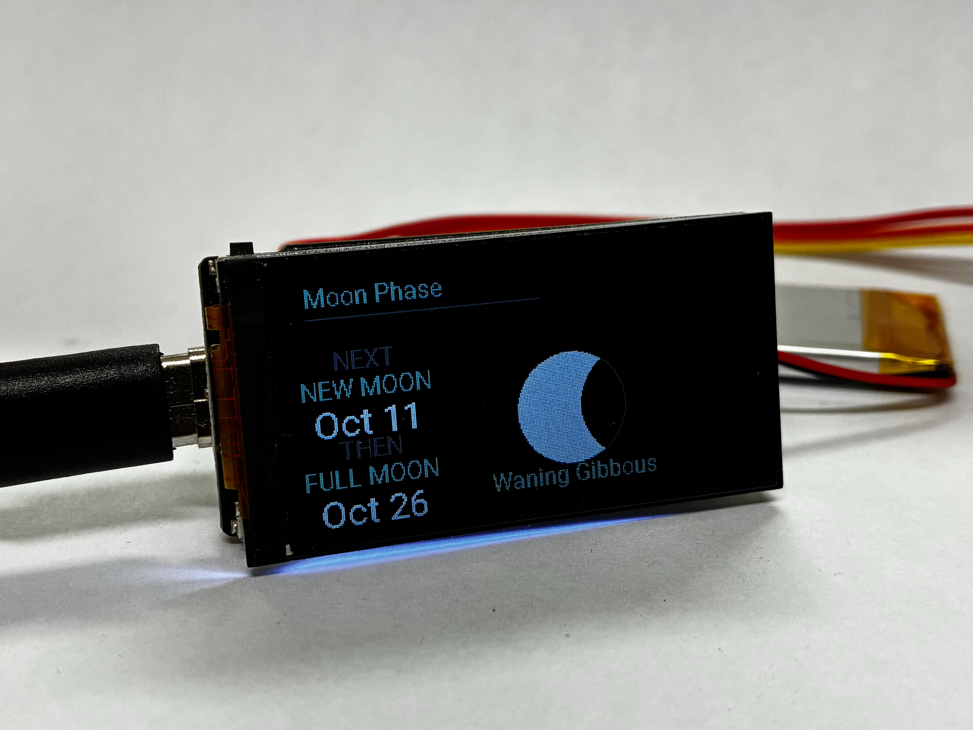
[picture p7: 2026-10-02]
hardware/Photos/espthsc/ESPTHSC-6.jpg

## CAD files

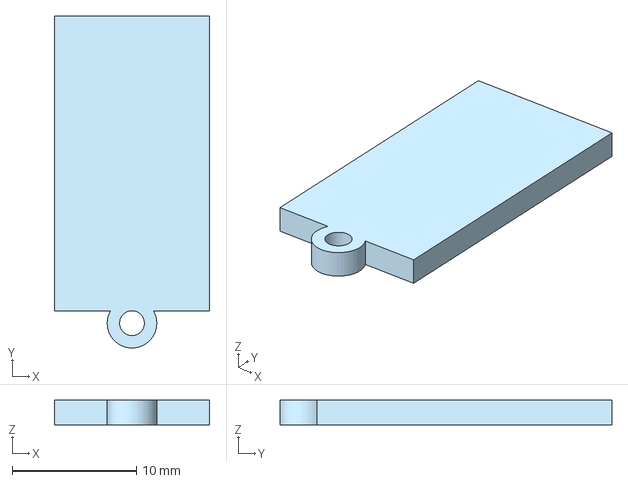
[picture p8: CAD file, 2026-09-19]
hardware/3D Print/espth_files/STEP/ESP32_C6_Holding_Plate-STEP.step
12.5 x 26.8 x 2.00 mm

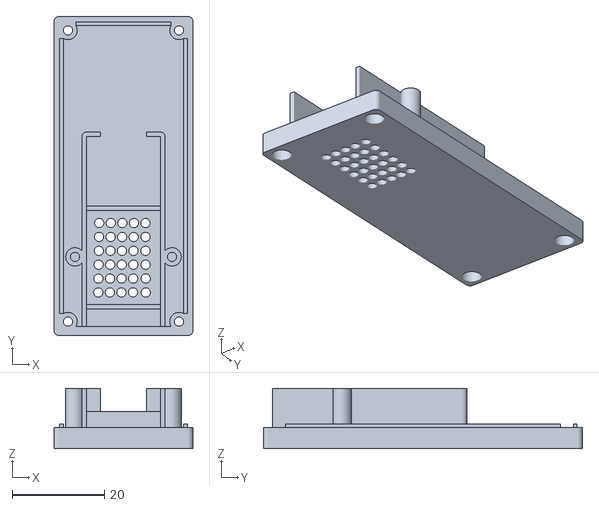
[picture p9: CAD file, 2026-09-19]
hardware/3D Print/espth_files/STL/espth_lid.stl
30.0 x 69.0 x 13.0

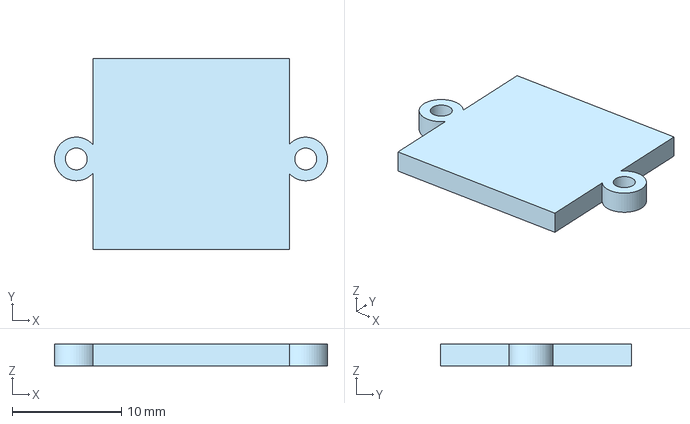
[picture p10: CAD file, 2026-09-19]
hardware/3D Print/espth_files/STEP/DHT22_Holding_Plate-STEP.step
25.0 x 17.5 x 2.00 mm

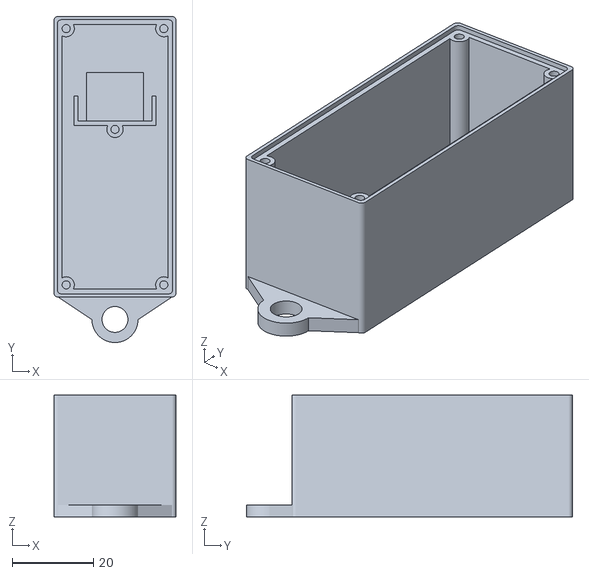
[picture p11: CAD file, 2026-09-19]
hardware/3D Print/espth_files/STL/espth_base.stl
30.0 x 80.2 x 30.0

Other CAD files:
hardware/3D Print/espth_files/STEP/espth_Lid-STEP.step
hardware/3D Print/espth_files/STL/DHT22_Holding_Plate.stl
hardware/3D Print/espth_files/STEP/espth_Base-STEP.step
hardware/3D Print/espth_files/STL/ESP32_C6_Holding_Plate.stl

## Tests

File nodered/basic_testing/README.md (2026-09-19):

# Node-RED and MQTT Setup

This folder contains a small diagnostic dashboard for the ESP32 Home Temperature Sensors project. It is deliberately separate from a full home-automation setup: its job is to prove that a sensor can publish temperature and humidity data, that the MQTT broker receives it, and that Node-RED can display it.

You do not need previous networking or Node-RED experience. Follow the sections in order.

For an always-on Pi dashboard with SQLite history and multiple sensors, use the [Raspberry Pi Zero 2 W standalone build](../pi_zero_2w_Standalone/) instead.

## Contents

- [How the data moves](#how-the-data-moves)
- [Before you begin](#before-you-begin)
- [Install Mosquitto](#install-mosquitto)
- [Configure and test the MQTT broker](#configure-and-test-the-mqtt-broker)
- [Install Node-RED and import the flow](#install-node-red-and-import-the-flow)
- [Configure the included flow](#configure-the-included-flow)
- [Use the diagnostic dashboard](#use-the-diagnostic-dashboard)
- [Troubleshooting](#troubleshooting)

## How the data moves

```text
ESP32 sensor -> Wi-Fi network -> Mosquitto MQTT broker -> Node-RED flow -> web dashboard
```

- The ESP32 sensor measures temperature and humidity, then publishes the reading.
- The Wi-Fi network carries that message. The sensor, MQTT broker, and Node-RED machine must be able to reach one another on the same local network. Do not use a guest Wi-Fi network that blocks connected devices from communicating.
- Mosquitto is the MQTT broker. Think of it as a local post office: sensors send it messages, and other programs subscribe to receive them.
- Node-RED subscribes to the broker, interprets the readings, and presents them in a browser dashboard.

Mosquitto and Node-RED can run on the same computer or Raspberry Pi. That is the easiest arrangement for this example.

Important: `localhost` always means the device running the software. It is correct for Node-RED when Mosquitto runs on the same machine. It is never correct in an ESP32 YAML file, because on the ESP32 `localhost` would mean the ESP32 itself. The sensor needs the local IP address or hostname of the machine running Mosquitto.

## Before you begin

Have these ready:

- A working ESP32 sensor that has joined your Wi-Fi network.
- A computer or Raspberry Pi that will run Mosquitto and Node-RED.
- A USB data cable for the ESP32's first firmware flash, if it has not already been flashed.
- The local IP address of the computer or Pi that will run Mosquitto. Use this address in the ESP32 MQTT configuration.

For the safest first test, use a trusted home or lab network. MQTT username/password authentication is optional for a temporary test, but should be enabled before leaving the broker running on a normal network.

The sensor uses TCP `1883` to reach Mosquitto. Your browser uses the port configured for your Node-RED installation, normally TCP `1880`. They are separate services. Allow these applications through the host firewall only for your trusted LAN; do not set up router port forwarding. This repository does not configure an editor login; before broader use, follow [Node-RED's security guide](https://nodered.org/docs/user-guide/runtime/securing-node-red). MQTT passwords on port `1883` are not encrypted in transit.

To find the broker computer's LAN address: run `ipconfig` in Windows PowerShell (active adapter's IPv4 address), `ipconfig getifaddr en0` on a typical Mac Wi-Fi connection (or look in System Settings > Network > Wi-Fi > Details > TCP/IP), or `hostname -I` on Linux/Pi (choose the address on the sensor's LAN, not a container/VPN address). An iPhone hotspot may restrict communication between clients; a successful internet connection alone does not prove local MQTT can connect.

## Install Mosquitto

Mosquitto is the MQTT broker. Install both the broker and its command-line tools; the tools let you prove the broker works before Node-RED is involved.

### Windows

1. Download and install Mosquitto from the official [Mosquitto download page](https://mosquitto.org/download/).
2. Open PowerShell after the installation completes.
3. Confirm the broker executable is available. If the installer did not add it to your PATH, use its usual installation location:

```powershell
& "C:\Program Files\mosquitto\mosquitto.exe" -h
```

### macOS

1. Install [Homebrew](https://brew.sh/) if you do not already use it.
2. Open Terminal and run:

```bash
brew install mosquitto
mosquitto -h
```

### Linux and Raspberry Pi OS

On Raspberry Pi OS, Ubuntu, Debian, and other Debian-based systems, run:

```bash
sudo apt update
sudo apt install -y mosquitto mosquitto-clients
```

The package may start a background Mosquitto service automatically. For this guide's foreground test, stop it first so the test broker can use port `1883`:

```bash
sudo systemctl stop mosquitto
```

See the [Mosquitto download page](https://mosquitto.org/download/) for other Linux distributions.

## Configure and test the MQTT broker

Start with an intentionally simple configuration so that you can verify the network path. Then add a username and password before treating the broker as a long-running home service.

### 1. Create a temporary test configuration

Create a file named `mosquitto.conf` in your home folder. Use this content:

An identical starting configuration is included as [mosquitto.example.conf](mosquitto.example.conf). Copy it into your home folder as `mosquitto.conf`, or create it below. Keep your real broker configuration and password file outside the repository.

```conf
listener 1883
allow_anonymous true
```

**Windows PowerShell**

```powershell
notepad "$HOME\mosquitto.conf"
```

**macOS, Linux, or Raspberry Pi**

```bash
nano ~/mosquitto.conf
```

Paste the configuration above, save the file, and close the editor. In Nano, press `Ctrl+O`, `Enter`, then `Ctrl+X`.

`1883` is the normal unencrypted MQTT port. `allow_anonymous true` means devices on your trusted local network can connect without a username or password. Do not use this setting on a network you do not trust.

### 2. Start the broker

Open a terminal and leave this command running. The `-v` option prints connection and message activity.

Only one broker can listen on port `1883`. If it is already in use, stop your test broker or the newly installed service first. On Windows, check the Mosquitto entry in Services; on macOS, check `brew services list` and use `brew services stop mosquitto` if you started it that way. Do not stop a broker serving other home devices without accounting for that interruption.

**Windows PowerShell**

```powershell
& "C:\Program Files\mosquitto\mosquitto.exe" -c "$HOME\mosquitto.conf" -v
```

**macOS**

```bash
mosquitto -c ~/mosquitto.conf -v
```

**Linux or Raspberry Pi**

```bash
mosquitto -c ~/mosquitto.conf -v
```

For now, run the Linux command as your normal user, without `sudo`, so it can read files in your home directory. A permanent system service uses a different configuration location and file permissions; see the service notes below after testing.

### 3. Prove the broker works before involving the sensor

Open a second terminal window. Run the subscribe command and leave it open.

**Windows PowerShell**

```powershell
& "C:\Program Files\mosquitto\mosquitto_sub.exe" -h localhost -p 1883 -t "test/temperature" -v
```

**macOS, Linux, or Raspberry Pi**

```bash
mosquitto_sub -h localhost -p 1883 -t "test/temperature" -v
```

Open a third terminal window and publish a test reading.

**Windows PowerShell**

```powershell
& "C:\Program Files\mosquitto\mosquitto_pub.exe" -h localhost -p 1883 -t "test/temperature" -m "72.4"
```

**macOS, Linux, or Raspberry Pi**

```bash
mosquitto_pub -h localhost -p 1883 -t "test/temperature" -m "72.4"
```

The subscribe terminal should print:

```text
test/temperature 72.4
```

This proves local publish/subscribe works on the broker computer. To test the network path, run the same publisher from a second computer on the sensor's network, replacing `localhost` with the broker's LAN address. Seeing its message in the subscriber confirms cross-device communication. The ESP32 connection test below is still necessary.

### 4. Optional: require an MQTT username and password

For a normal home deployment, use a password rather than anonymous access.

1. Create a password file. The command will prompt for a password instead of placing it in your terminal history.

`-c` creates a new file and overwrites an existing one. Omit `-c` when updating an account or adding another user to an existing file.

**Windows PowerShell**

```powershell
& "C:\Program Files\mosquitto\mosquitto_passwd.exe" -c "$HOME\mosquitto.passwd" example_sensor_user
```

**macOS, Linux, or Raspberry Pi**

```bash
mosquitto_passwd -c ~/mosquitto.passwd example_sensor_user
```

2. Replace the contents of `mosquitto.conf` with the following. Replace the password-file path with the full path to the file you just created. On Windows, use forward slashes in the path, such as `C:/Users/YOUR_WINDOWS_USERNAME/mosquitto.passwd`.

```conf
listener 1883
allow_anonymous false
password_file /full/path/to/mosquitto.passwd
```

3. Stop the running broker with `Ctrl+C`, then start it again using the command for your operating system above.
4. Retest with a username and password. Substitute your own password:

**Windows PowerShell**

```powershell
& "C:\Program Files\mosquitto\mosquitto_sub.exe" -h localhost -p 1883 -u example_sensor_user -P "YOUR_PASSWORD" -t "test/temperature" -v
```

**macOS, Linux, or Raspberry Pi**

```bash
mosquitto_sub -h localhost -p 1883 -u example_sensor_user -P "YOUR_PASSWORD" -t "test/temperature" -v
```

In another terminal, publish an authenticated test message:

**Windows PowerShell**

```powershell
& "C:\Program Files\mosquitto\mosquitto_pub.exe" -h localhost -p 1883 -u example_sensor_user -P "YOUR_PASSWORD" -t "test/temperature" -m "72.4"
```

**macOS, Linux, or Raspberry Pi**

```bash
mosquitto_pub -h localhost -p 1883 -u example_sensor_user -P "YOUR_PASSWORD" -t "test/temperature" -m "72.4"
```

Expect `test/temperature 72.4` again. The `-P` examples expose the password in command history and potentially the process list; use temporary test credentials, and do not share terminal output or screenshots containing them.

The ESP32 YAML and Node-RED broker settings must use the same port, username, and password. Mosquitto's documentation covers [password files](https://mosquitto.org/documentation/authentication-methods/) and [listener settings](https://mosquitto.org/man/mosquitto-conf-5.html) in more depth.

### 5. Connect the ESP32

Both ESP32 YAMLs already read the MQTT connection from private `firmware/secrets.yaml`. Copy [secrets.example.yaml](../../firmware/secrets.example.yaml) to that filename as described in the [firmware guide](../../firmware/README.md). Set `mqtt_broker` to the Mosquitto computer's LAN address. The public YAML should retain these references:

```yaml
mqtt:
  broker: !secret mqtt_broker
  port: 1883
  username: !secret mqtt_username
  password: !secret mqtt_password
```

Flash or update the sensor, then watch the Mosquitto terminal. A successful connection appears there. To see every topic from the sensor, use the version for your operating system below.

**Windows PowerShell**

```powershell
& "C:\Program Files\mosquitto\mosquitto_sub.exe" -h localhost -p 1883 -u example_sensor_user -P "YOUR_PASSWORD" -t "#" -v
```

**macOS, Linux, or Raspberry Pi**

```bash
mosquitto_sub -h localhost -p 1883 -u example_sensor_user -P "YOUR_PASSWORD" -t "#" -v
```

If you chose anonymous access for the temporary test, remove `-u example_sensor_user -P "YOUR_PASSWORD"` from the command.

For that anonymous test, also set `mqtt_username: ""` and `mqtt_password: ""` in private `secrets.yaml`, and leave the Node-RED broker Security fields empty. With authentication enabled, all three clients must use the account created above.

Expected sensor traffic is `<device_name>/telemetry` JSON every minute for ESPTHSC, or separate `<device_name>/sensor/temperature/state` and `humidity/state` readings every 15 minutes for ESPTH. The screen also publishes other ESPHome entity states. Seeing those messages in the subscriber confirms that the real sensor is reaching the broker.

### 6. Optional: a permanent Linux/Pi broker service

After the foreground test works, stop it with `Ctrl+C`. For a new dedicated broker, edit `/etc/mosquitto/conf.d/temperature.conf` using `sudo nano /etc/mosquitto/conf.d/temperature.conf`. Add the listener and authentication settings above, but use `password_file /etc/mosquitto/temperature.passwd`. Create that file and start the service:

```bash
sudo mosquitto_passwd -c /etc/mosquitto/temperature.passwd example_sensor_user
sudo chown root:mosquitto /etc/mosquitto/temperature.passwd
sudo chmod 640 /etc/mosquitto/temperature.passwd
sudo systemctl enable --now mosquitto
sudo systemctl restart mosquitto
sudo journalctl -u mosquitto -n 30 --no-pager
```

Use `-c` only for a new password file. Confirm `/etc/mosquitto/mosquitto.conf` includes `/etc/mosquitto/conf.d`, and avoid duplicate listeners if other broker configuration already exists. This service setup applies to Debian-based installations; it does not use the test `~/mosquitto.conf` automatically.

## Install Node-RED and import the flow

This repository supplies an example flow, not a complete Node-RED installation. Install, secure, and run Node-RED using the method that suits your computer or Raspberry Pi. The official [Node-RED installation guides](https://nodered.org/docs/getting-started/) cover Windows, macOS, Linux, and Raspberry Pi.

The flow needs the **FlowFuse Dashboard** add-on because it uses Dashboard 2.0 nodes such as `ui-base`, `ui-page`, and `ui-text`.

1. Install and start Node-RED using the official guide for your operating system.
2. Open its editor. A standard local installation uses `http://localhost:1880`. If yours uses a different port, use that address throughout this guide.
3. In the editor menu, choose **Manage palette**, open the **Install** tab, search for `@flowfuse/node-red-dashboard`, and install it. Restart Node-RED if prompted.
4. Choose the editor menu, then **Import**. Select [espth-diag-flows.json](espth-diag-flows.json) from this folder and import it.
5. The imported **Temperature Diagnostics** tab appears in the workspace. Importing adds this tab to your existing flows; it does not replace them.

The example uses the standard Node-RED dashboard route `/dashboard/diagnostics`. Its full address is normally `http://localhost:1880/dashboard/diagnostics`.

## Configure the included flow

Import [espth-diag-flows.json](espth-diag-flows.json) using the steps above, then configure it before clicking **Deploy**. The flow has no saved MQTT username or password.

### 1. Set the MQTT broker details

1. Open the Node-RED editor, normally at `http://localhost:1880`.
2. Find and double-click the node named **Sensor MQTT input**.
3. Select the topic for **one indoor sensor**. The default is `espthsc-1/telemetry` for the screen sensor. Use `espth-1/sensor/+/state` for the no-screen sensor. Replace the device name if you changed it in YAML. Avoid `#` here: the broker can carry readings from multiple devices and the display's outside weather sensors.
4. Next to the server field named **Local Mosquitto**, click the pencil icon.
5. Set the broker host:
   - Use `localhost` when Mosquitto and Node-RED run on the same computer or Pi.
   - Use the broker machine's local IP address or hostname when Mosquitto runs elsewhere.
6. Set the port to `1883`, unless you deliberately changed the Mosquitto listener to another port.
7. Open the security settings and enter the MQTT username/password if you enabled authentication.
8. Click **Update**, then **Done**, then **Deploy**.

The MQTT input node should show **connected** beneath it after deployment. If it does not, return to the terminal MQTT test before changing the flow further.

The broker client ID is left blank so Node-RED can generate one; if you set it manually, use a unique ID for every running client. Duplicate IDs can make clients disconnect each other. If you change the MQTT port, update Mosquitto's listener, both YAMLs, this broker configuration, and your test commands together. The Node-RED browser port is controlled by your own Node-RED installation and does not need to match the MQTT port.

### 2. What the flow expects

The parser accepts the indoor numeric state topics produced by the example YAMLs (the supplied numeric temperature states are Fahrenheit):

```text
espthsc-1/sensor/indoor_temperature/state 70.2
espthsc-1/sensor/indoor_humidity/state 51.4
espth-1/sensor/temperature/state 70.2
espth-1/sensor/humidity/state 51.4
```

It also accepts combined JSON on `<device_name>/telemetry`, which is the recommended screen input:

```json
{
  "timestamp": 1700000000,
  "temperature_f": 70.2,
  "humidity_percent": 51.4
}
```

Telemetry accepts `temperature_f` or `temperature_c`, `humidity_percent`, and an optional `timestamp` (Unix seconds, Unix milliseconds, or a parseable date string). It retains the latest temperature and humidity for the same device so separate messages produce one reading. Outside weather, debug/status messages, malformed JSON, and invalid values are ignored. When a different device supplies data, previous values are cleared to avoid combining two devices. Pressure and battery fields are not shown on this dashboard.

This is a one-device diagnostic view. To compare rooms simultaneously, extend the flow with separate device state and widgets. If you change the firmware's numeric state topics to Celsius, also update the parser's default unit; changing just the label does not convert a measurement.

## Use the diagnostic dashboard

Open:

```text
http://localhost:1880/dashboard/diagnostics
```

The Diagnostics page should show:

- The latest temperature reading.
- The latest humidity reading.
- The timestamp of the latest valid temperature reading. Telemetry uses its source timestamp when supplied; plain state topics use the Node-RED receive time. A humidity-only update does not advance this timestamp.

Before readings arrive, widgets may be empty; after a partial reading, missing values show `No reading yet`. Wait for the sensor's sample interval. The screen telemetry interval is one minute; the no-screen interval is 15 minutes. Enable **Raw MQTT (enable to inspect)** in the editor and open the Debug sidebar to inspect incoming messages. Disable it after testing, and scrub payloads before sharing screenshots or logs. The flow does not store history or mark stale readings automatically; retained MQTT state can be older than its receive timestamp.

## Troubleshooting

| Symptom | Check |
| --- | --- |
| `mosquitto_sub` does not receive the test message | Confirm the broker is still running, use the same port in both commands, and check the broker terminal for errors. |
| ESP32 cannot connect | Use the Mosquitto machine's LAN IP in the ESP32 YAML, not `localhost`. Confirm the ESP32 and broker are on the same non-guest network and allow Mosquitto through the computer firewall. |
| Node-RED MQTT node says disconnected | Confirm host, port, username, and password match the working terminal test. Use `localhost` only when Node-RED and Mosquitto run on the same machine. |
| Dashboard page does not open | Confirm Node-RED is running, FlowFuse Dashboard is installed, and use the port configured by your Node-RED installation. The usual default is `1880`. |
| Dashboard opens but has no readings | Repeat the OS-specific subscriber command above with your actual broker host, port, and credentials. Confirm the input topic matches the device name. Enable the supplied Debug node and wait for the sensor interval. |
| Another computer cannot open the editor/dashboard | Replace `localhost` in the browser URL with the Node-RED machine's IP address. Check that the firewall permits your configured Node-RED port, normally `1880`. |

Once this diagnostic setup works, you have a clean foundation for a larger dashboard, alerts, room labels, historical storage, and your broader home temperature-sensor system.

## Sharing and Attribution

The root `.gitignore` excludes Node-RED runtime configuration, credentials, sessions, and backups. They can contain private paths, passwords, or the key needed to decrypt `flows_cred.json`. Never upload a running Node-RED user directory wholesale. Review changes to [espth-diag-flows.json](espth-diag-flows.json) before committing because broker addresses and custom payloads can be saved there. Enter your broker login in your own Node-RED editor; credentials are not supplied by this project.

The flow and this guide were developed with AI assistance and use [GPL-3.0-only](../../LICENSE). FlowFuse Dashboard and Node-RED retain their upstream licenses. See [NOTICE.md](../../NOTICE.md).

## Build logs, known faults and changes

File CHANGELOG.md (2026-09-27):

# Changelog

## 27 September, 2026 Release

### Changed
- Switched ESPTHSC indoor sensing from BME280 to DHT22 on GPIO6.
- Reordered the ESPTHSC display sequence.
- Added a 12-hour weather outlook.
- Added wind speed, direction, and gust alerts.
- Improved BOOT-button click handling.

### Documentation
- Updated ESPTHSC hardware, wiring, display, and control instructions.

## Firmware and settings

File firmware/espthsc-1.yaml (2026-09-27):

# SPDX-License-Identifier: GPL-3.0-only
# Developed with AI assistance. Review and test before deployment; see ../NOTICE.md.
substitutions:
  device_name: espthsc-1
  friendly_name: Waveshare Weather Display

esphome:
  name: ${device_name}
  friendly_name: ${friendly_name}
  on_boot:
    priority: -10
    then:
      - lambda: |-
          id(display_blank) = false;
          id(clock_pinned) = false;
          id(screen_index) = 0;
          id(main_display).update();
      - light.turn_off: onboard_rgb_led
      - script.execute: apply_backlight
      - delay: 30s
      - if:
          condition:
            lambda: return id(wifi_ready);
          then:
            - script.execute: fetch_weather
          else:
            - lambda: |-
                id(weather_status) = "Waiting for Wi-Fi";
                id(main_display).update();

esp32:
  board: esp32-s3-devkitc-1
  framework:
    type: arduino

logger:
  level: INFO

# Optional MQTT telemetry for the home temperature sensor network.
# Uncomment this block and the telemetry publish action below to enable it.
# mqtt:
#   broker: !secret mqtt_broker
#   port: 1883
#   discovery: false
#   # Keep the display and its in-memory forecast alive when the broker is unavailable.
#   reboot_timeout: 0s
#   log_topic: ${device_name}/debug
#   username: !secret mqtt_username
#   password: !secret mqtt_password

ota:
  - platform: esphome
    password: !secret ota_password

wifi:
  # Keep cached weather and sensor state alive while a temporary hotspot is offline.
  reboot_timeout: 0s
  networks:
    - ssid: !secret wifi_ssid
      password: !secret wifi_password
  fast_connect: false
  power_save_mode: none
  ap:
    ssid: "${device_name} Setup"
    password: !secret fallback_ap_password
  on_connect:
    then:
      - lambda: |-
          id(wifi_ready) = true;
          id(weather_status) = "Wi-Fi connected";
          id(main_display).update();
          ESP_LOGI("weather", "Wi-Fi connected; weather fetch queued");
      - delay: 12s
      - script.execute: fetch_weather
  on_disconnect:
    then:
      - lambda: |-
          id(wifi_ready) = false;
          id(weather_status) = id(hourly_cache_valid) ? "Wi-Fi lost; using forecast" : "Waiting for Wi-Fi";
          id(main_display).update();

captive_portal:

time:
  - platform: sntp
    id: local_time
    timezone: !secret timezone
    on_time_sync:
      then:
        - lambda: |-
            auto now = id(local_time).now();
            if (now.is_valid()) {
              id(stored_clock_epoch) = now.timestamp;
              id(stored_clock_millis) = millis();
              ESP_LOGI("clock", "Stored synced clock fallback");
            }

http_request:
  id: weather_http
  timeout: 10s
  verify_ssl: false
  useragent: ESPHome Waveshare Weather Display

spi:
  clk_pin: GPIO10
  mosi_pin: GPIO13

output:
  - platform: ledc
    id: lcd_backlight_pwm
    pin:
      number: GPIO14
      inverted: true
    frequency: 1000 Hz
    zero_means_zero: true

light:
  - platform: monochromatic
    id: lcd_backlight
    name: "LCD Backlight"
    output: lcd_backlight_pwm
    restore_mode: ALWAYS_OFF
    default_transition_length: 250ms

  - platform: neopixelbus
    id: onboard_rgb_led
    name: "Onboard RGB LED"
    pin: GPIO15
    num_leds: 2
    type: GRB
    variant: WS2812
    restore_mode: ALWAYS_OFF
    default_transition_length: 0s
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
